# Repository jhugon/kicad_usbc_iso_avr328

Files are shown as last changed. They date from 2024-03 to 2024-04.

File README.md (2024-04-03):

# KiCad USB-C isolated ATmega328

A USB-C to serial converter connected through opto-isolators to an ATmega328.
Power for the isolated side comes through another USB-C port.

All runs on the 4V DC that comes through the USB ports and everything is
through-hole.

Notable parts are the USB-serial converter, a MCP2221A-I/P, the isolators,
ACPL-772L-000E, and the microcontroller, ATmega328P-PU.

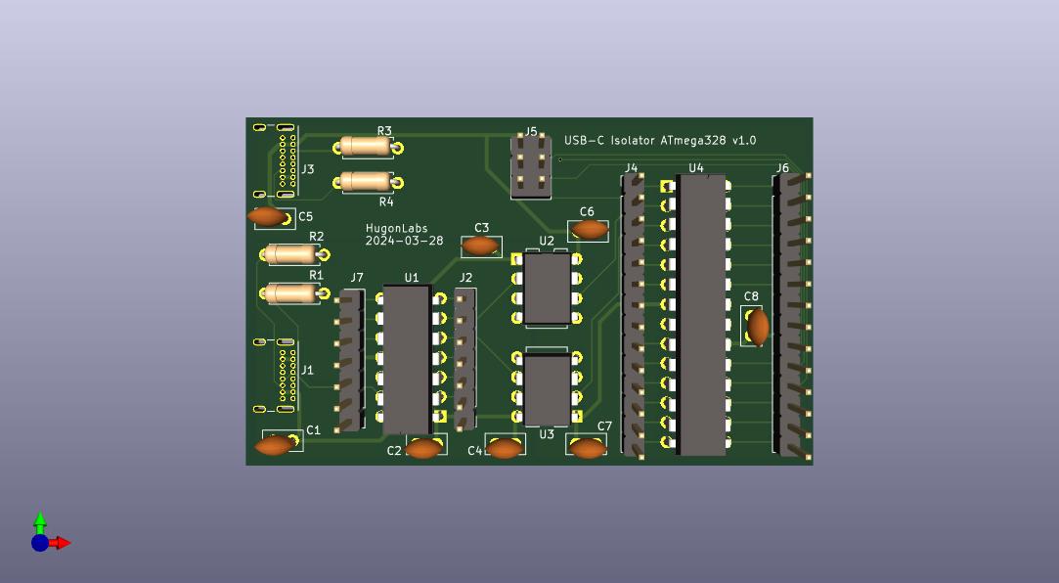
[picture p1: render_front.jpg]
Front PCB render


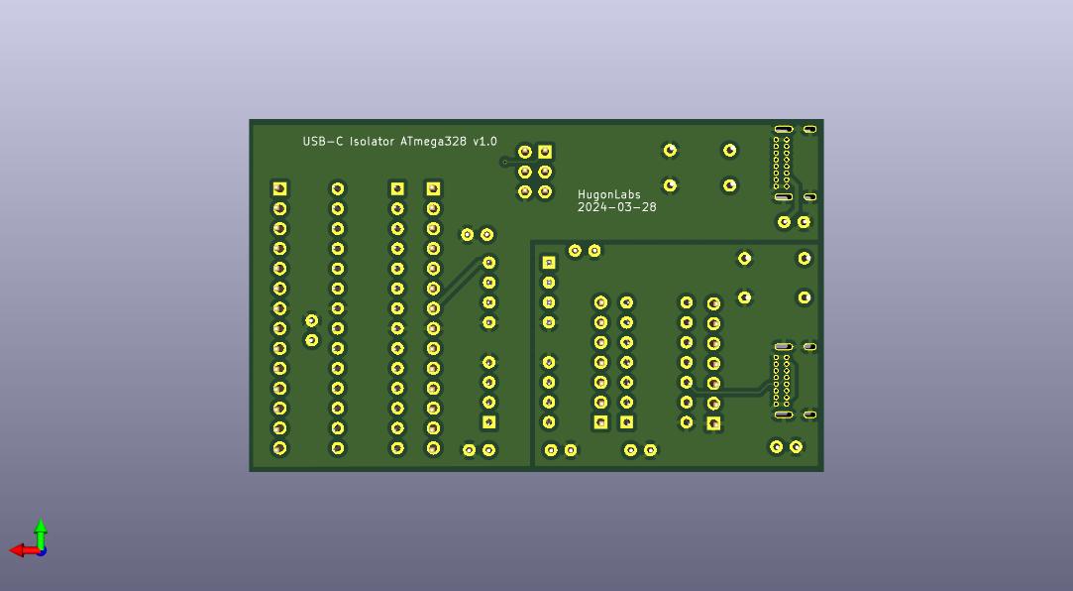
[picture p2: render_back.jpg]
Back PCB render


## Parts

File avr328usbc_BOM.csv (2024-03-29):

Reference | Value | Datasheet | Footprint | Qty | DNP | Description | MFR Part Num | MFR
C1,C5 | 10u | ~ | Capacitor_THT:C_Disc_D5.0mm_W2.5mm_P2.50mm | 2 |  | Unpolarized capacitor | FG14X7R1A106KRT00 | TDK
C2,C3,C4,C6,C7,C8 | 0u1 | ~ | Capacitor_THT:C_Disc_D5.0mm_W2.5mm_P2.50mm | 6 |  | Unpolarized capacitor | FG18X7R1H104KNT00 | TDK
J1,J3 | USB-C THT | https://www.usb.org/sites/default/files/documents/usb_type-c.zip | AAAA_Project_Library:USB_C_Receptacle_GCT_USB4085_Reduced_Pad_Size | 2 |  | USB 2.0-only 16P Type-C Receptacle connector | USB4085 | GCT
J2,J7 | MCP Debug Header | ~ | Connector_PinHeader_2.54mm:PinHeader_1x07_P2.54mm_Vertical | 2 | DNP | Generic connector, single row, 01x07, script generated (kicad-library-utils/schlib/autogen/connector/) | 9-146280-0 | TE Connectivity
J4,J6 | Conn_01x14_MountingPin | ~ | Connector_PinHeader_2.54mm:PinHeader_1x14_P2.54mm_Vertical | 2 | DNP | Generic connector, single row, 01x14, script generated (kicad-library-utils/schlib/autogen/connector/) | 9-146280-0 | TE Connectivity
J5 | AVR-ISP-6 | ~ | Connector_PinHeader_2.54mm:PinHeader_2x03_P2.54mm_Vertical | 1 |  | Atmel 6-pin ISP connector | 90130-1206 | Molex
R1,R2,R3,R4 | 5k1 | ~ | Resistor_THT:R_Axial_DIN0207_L6.3mm_D2.5mm_P7.62mm_Horizontal | 4 |  | 20% or better from USB Spec | MF1/4LCT52R512J | KOA Speer
U1 | MCP2221AxP | http://ww1.microchip.com/downloads/en/DeviceDoc/20005565B.pdf | Package_DIP:DIP-14_W7.62mm | 1 |  | USB to I2C/UART Protocol Converter with GPIO, DIP-14 | MCP2221A-I/P | Microchip
U2,U3 | ACPL-772L-000E | https://www.broadcom.com/products/optocouplers/industrial-plastic/digital-optocouplers/high-speed-cmos/acpl-772l-000e | Package_DIP:DIP-8_W7.62mm | 2 |  | High Speed CMOS Optocoupler in DIP 8 | ACPL-772L-000E | Broadcom
U4 | ATmega328P-P | http://ww1.microchip.com/downloads/en/DeviceDoc/ATmega328_P%20AVR%20MCU%20with%20picoPower%20Technology%20Data%20Sheet%2040001984A.pdf | Package_DIP:DIP-28_W7.62mm | 1 |  | 20MHz, 32kB Flash, 2kB SRAM, 1kB EEPROM, DIP-28 | ATmega328P-PU | Microchip

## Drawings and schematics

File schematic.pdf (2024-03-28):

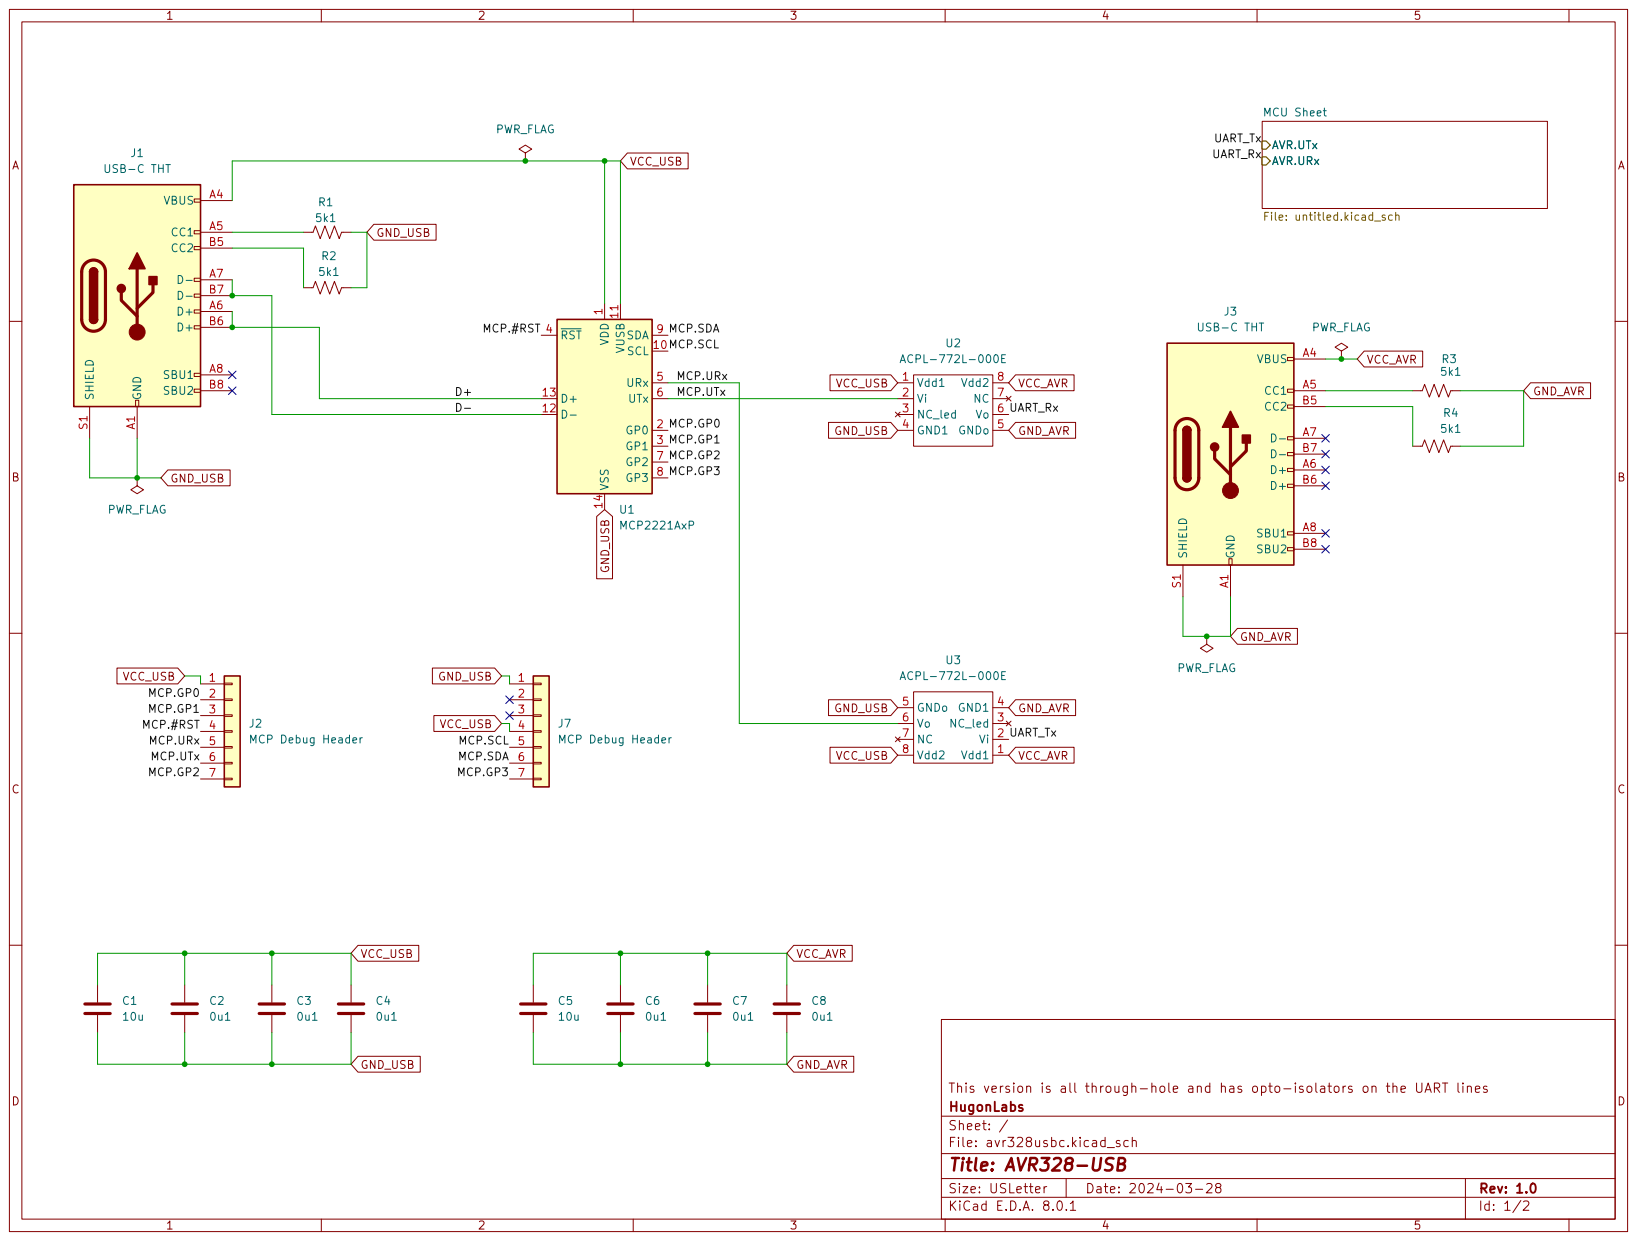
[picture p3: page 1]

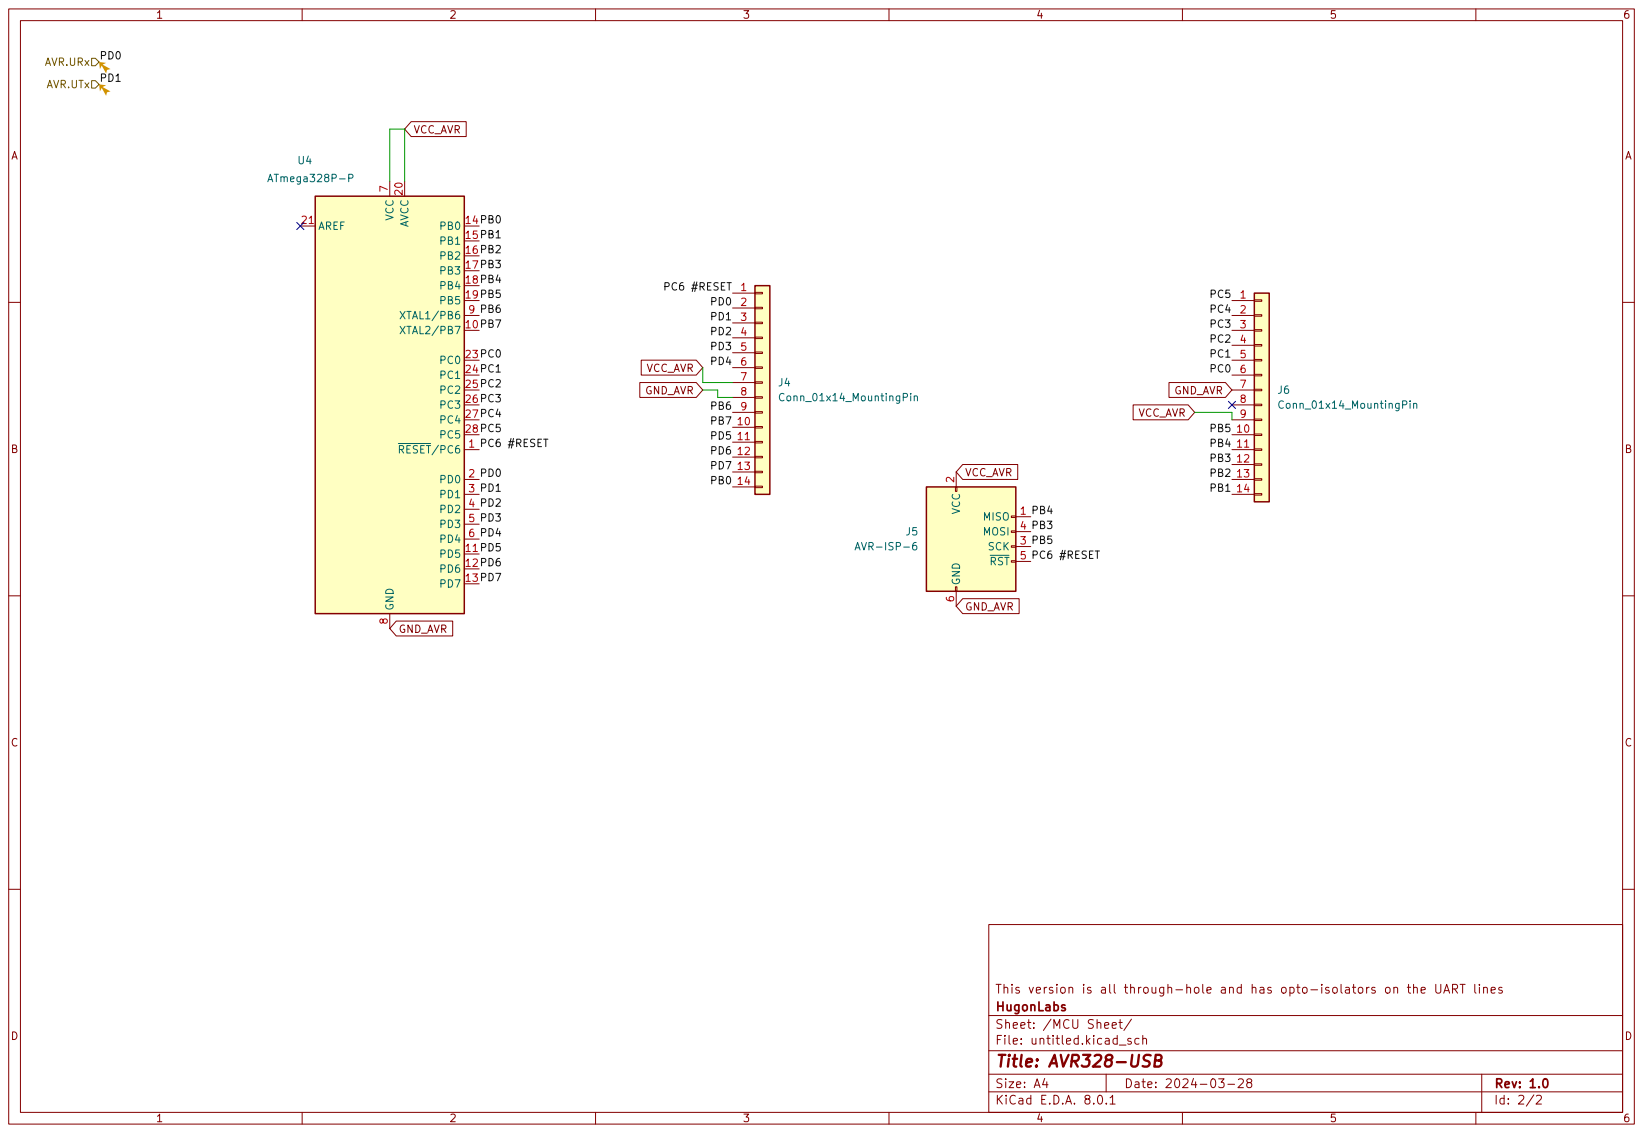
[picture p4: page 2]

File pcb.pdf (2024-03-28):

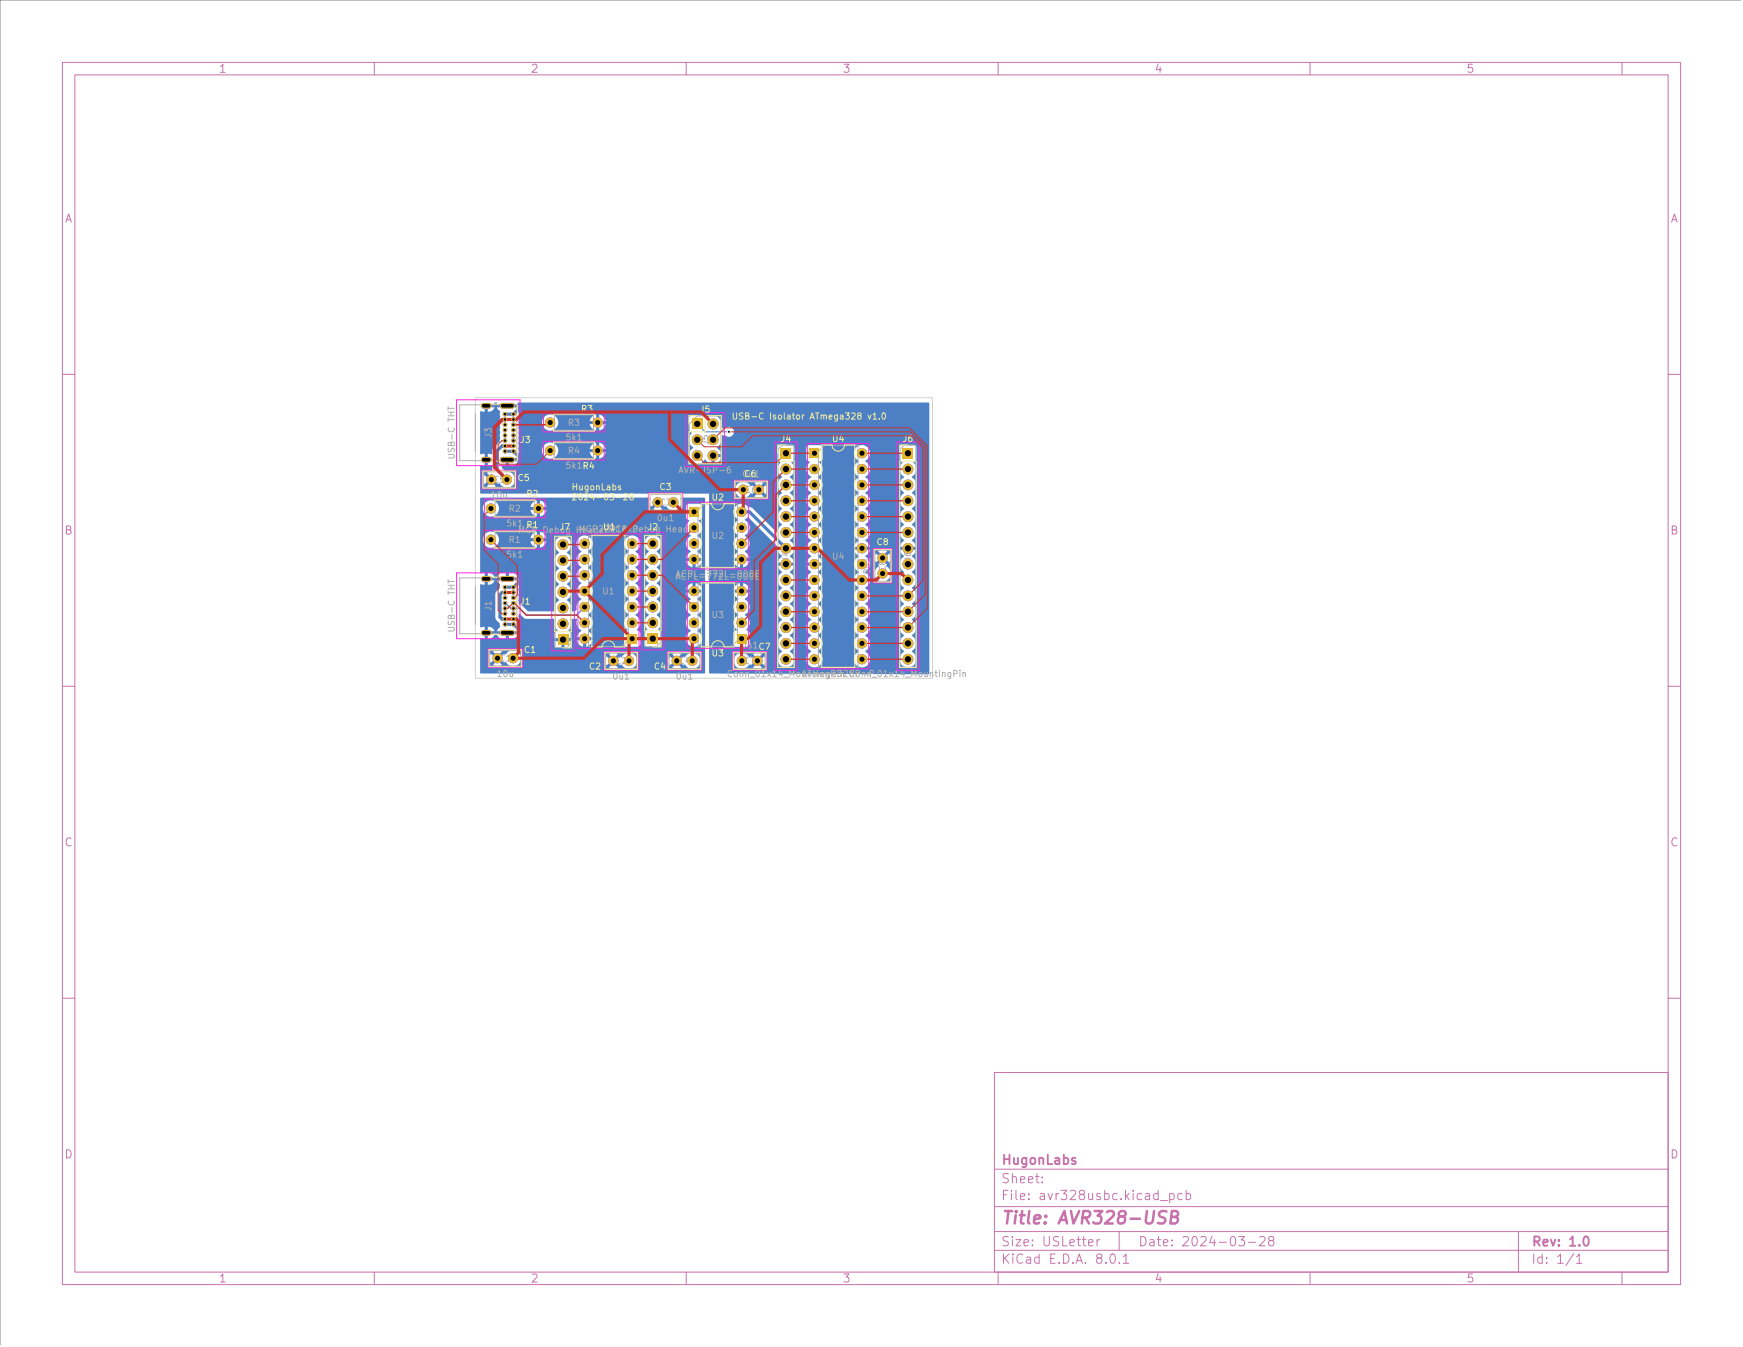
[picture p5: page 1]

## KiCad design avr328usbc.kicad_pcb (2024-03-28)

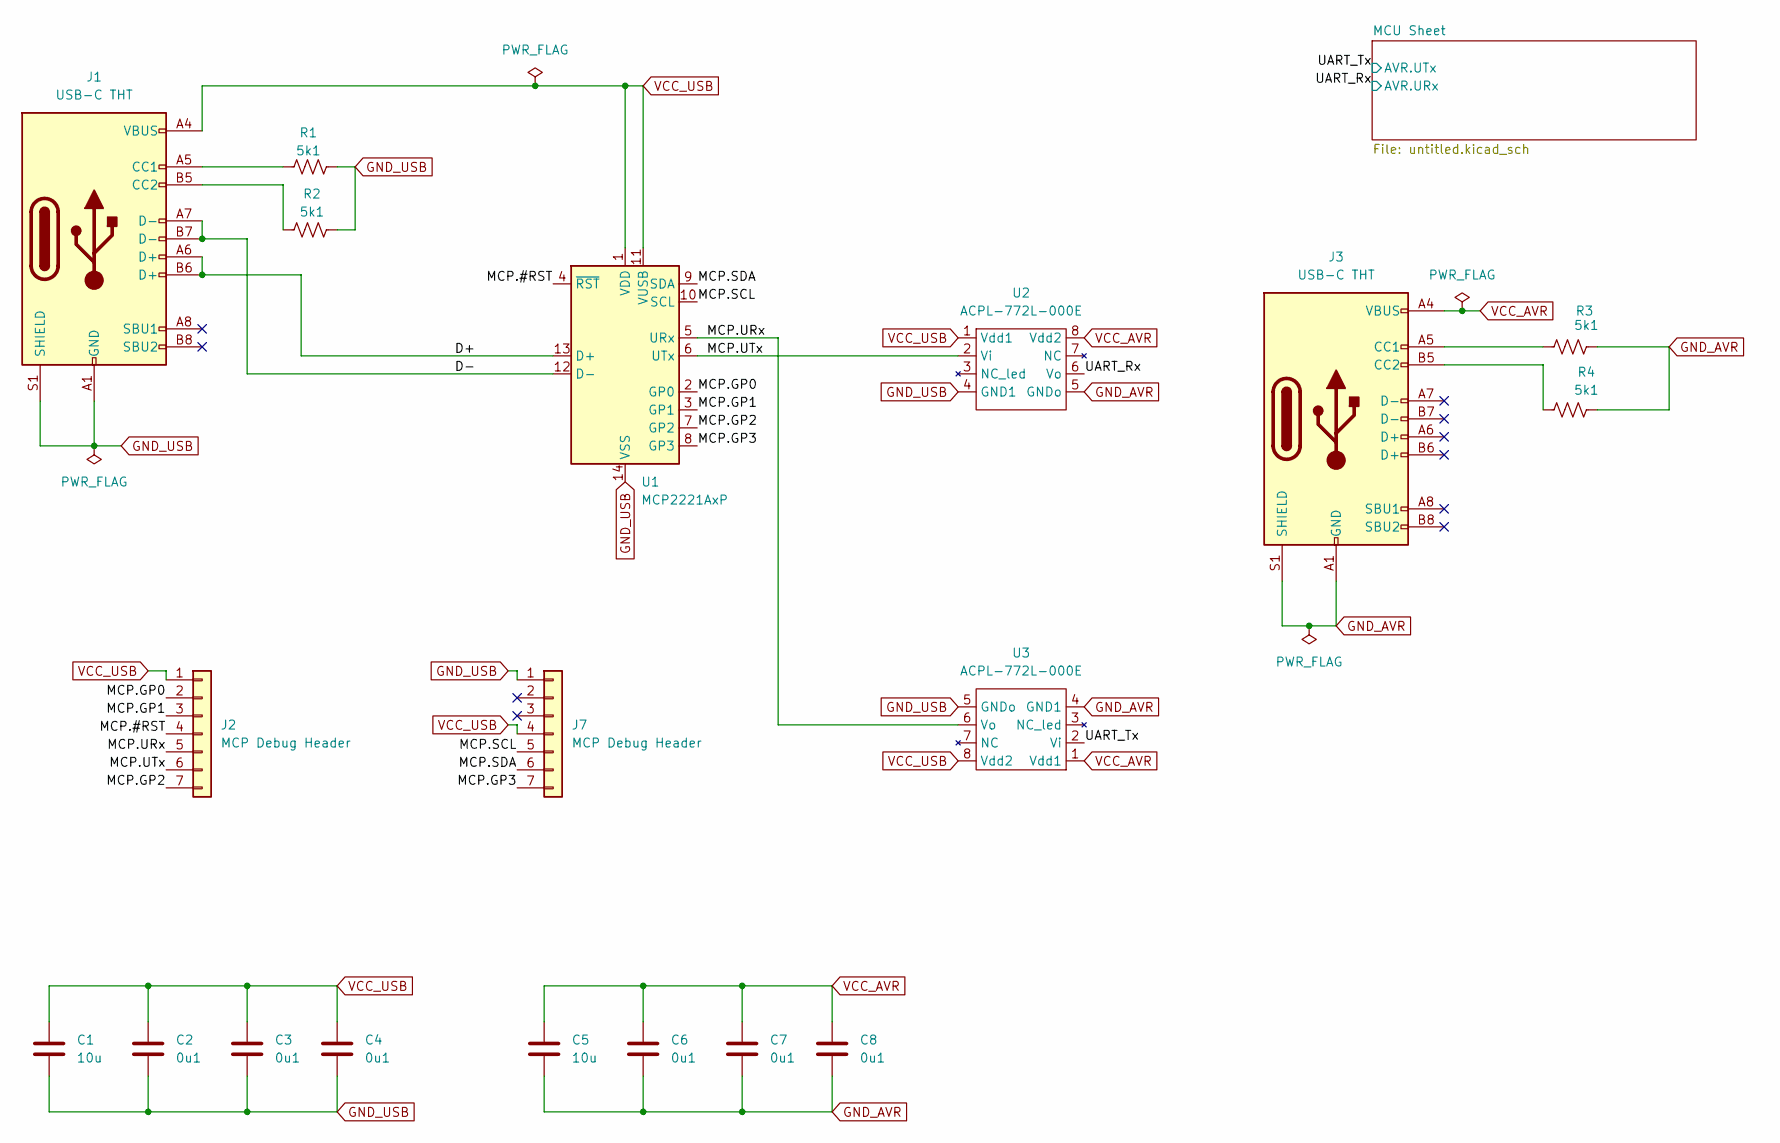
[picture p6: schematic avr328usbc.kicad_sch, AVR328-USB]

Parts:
C1, C5: 10u; C_Disc_D5.0mm_W2.5mm_P2.50mm; MFR Part Num FG14X7R1A106KRT00
C2, C3, C4, C6, C7, C8: 0u1; C_Disc_D5.0mm_W2.5mm_P2.50mm; MFR Part Num FG18X7R1H104KNT00
J1, J3: USB-C THT; USB_C_Receptacle_GCT_USB4085_Reduced_Pad_Size; MFR Part Num USB4085
J2, J7: MCP Debug Header; PinHeader_1x07_P2.54mm_Vertical; MFR Part Num 825433-7
R1, R2, R3, R4: 5k1; R_Axial_DIN0207_L6.3mm_D2.5mm_P7.62mm_Horizontal; MFR Part Num MF1/4LCT52R512J
U1: MCP2221AxP; DIP-14_W7.62mm; MFR Part Num MCP2221A-I/P
U2, U3: ACPL-772L-000E; DIP-8_W7.62mm; MFR Part Num ACPL-772L-000E

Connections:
/D+: J1.A6 (D+), J1.B6 (D+), U1.13 (D+)
/D-: J1.A7 (D-), J1.B7 (D-), U1.12 (D-)
/MCP.#RST: J2.4, U1.4 (~RST)
/MCP.GP0: J2.2, U1.2 (GP0)
/MCP.GP1: J2.3, U1.3 (GP1)
/MCP.GP2: J2.7, U1.7 (GP2)
/MCP.GP3: J7.7, U1.8 (GP3)
/MCP.SCL: J7.5, U1.10 (SCL)
/MCP.SDA: J7.6, U1.9 (SDA)
/MCP.URx: J2.5, U1.5 (URx), U3.6 (Vo)
/MCP.UTx: J2.6, U1.6 (UTx), U2.2 (Vi)
/UART_Rx: U2.6 (Vo); also elsewhere on the board
/UART_Tx: U3.2 (Vi); also elsewhere on the board
GND_AVR: C5.1, C6.1, C7.1, C8.1, J3.A1 (GND), J3.A12 (GND), J3.B1 (GND), J3.B12 (GND), J3.S1 (SHIELD), R3.2, R4.2, U2.5 (GNDo), U3.4 (GND1); also elsewhere on the board
GND_USB: C1.1, C2.1, C3.1, C4.1, J1.A1 (GND), J1.A12 (GND), J1.B1 (GND), J1.B12 (GND), J1.S1 (SHIELD), J7.1, R1.2, R2.2, U1.14 (VSS), U2.4 (GND1), U3.5 (GNDo)
unnamed: J1.A5 (CC1), R1.1
unnamed: J1.B5 (CC2), R2.1
unnamed: J3.A5 (CC1), R3.1
unnamed: J3.B5 (CC2), R4.1
VCC_AVR: C5.2, C6.2, C7.2, C8.2, J3.A4 (VBUS), J3.A9 (VBUS), J3.B4 (VBUS), J3.B9 (VBUS), U2.8 (Vdd2), U3.1 (Vdd1); also elsewhere on the board
VCC_USB: C1.2, C2.2, C3.2, C4.2, J1.A4 (VBUS), J1.A9 (VBUS), J1.B4 (VBUS), J1.B9 (VBUS), J2.1, J7.4, U1.1 (VDD), U1.11 (VUSB), U2.1 (Vdd1), U3.8 (Vdd2)

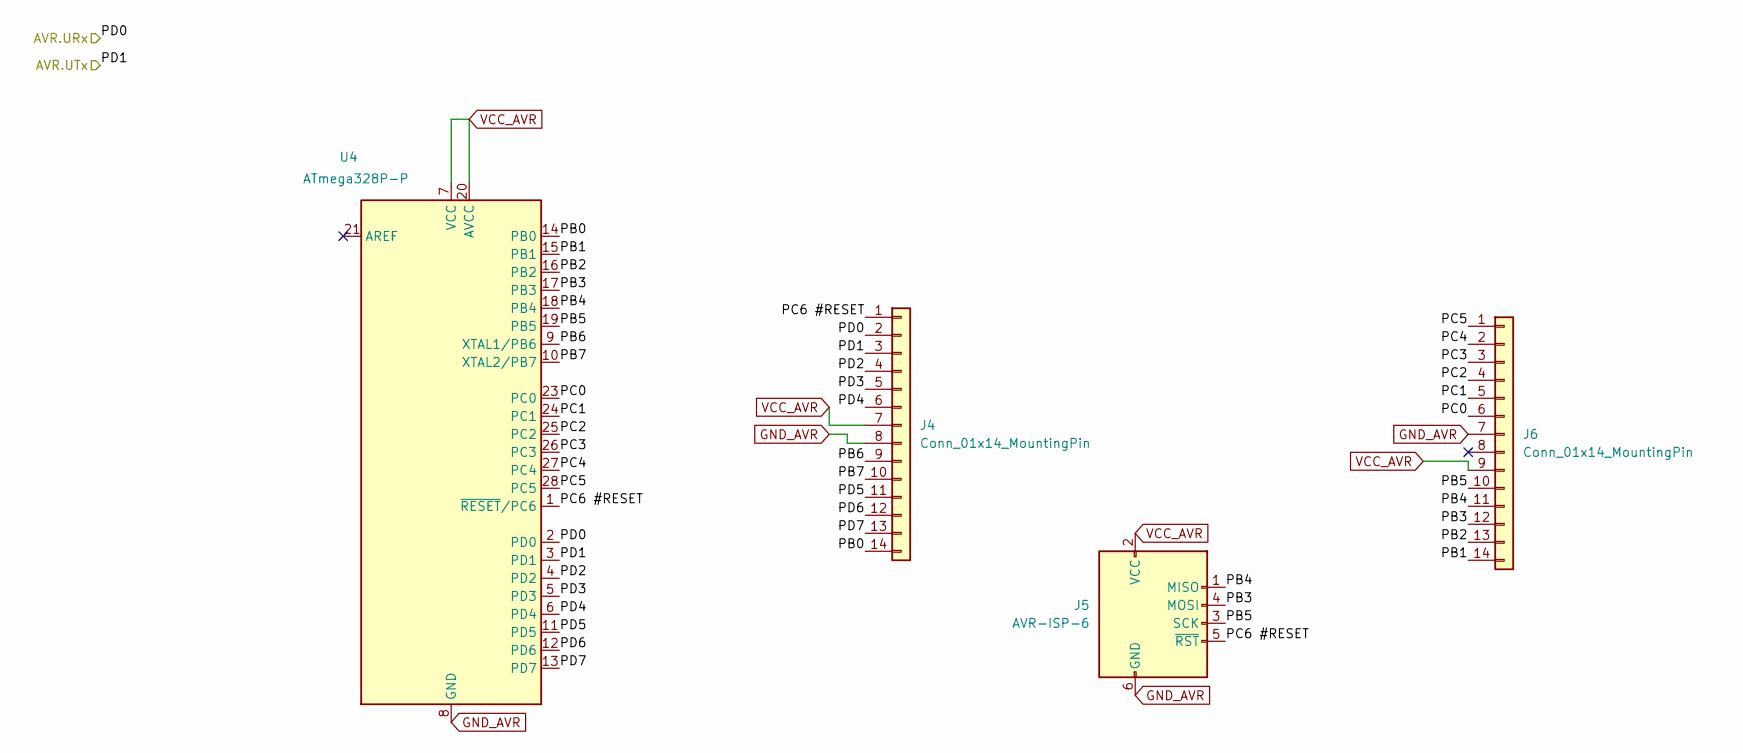
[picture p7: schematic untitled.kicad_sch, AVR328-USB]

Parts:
J4, J6: Conn_01x14_MountingPin; PinHeader_1x14_P2.54mm_Vertical
J5: AVR-ISP-6; PinHeader_2x03_P2.54mm_Vertical
U4: ATmega328P-P; DIP-28_W7.62mm; MFR Part Num ATmega328P-PU

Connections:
/MCU Sheet/PB0: J4.14, U4.14 (PB0)
/MCU Sheet/PB1: J6.14, U4.15 (PB1)
/MCU Sheet/PB2: J6.13, U4.16 (PB2)
/MCU Sheet/PB3: J5.4 (MOSI), J6.12, U4.17 (PB3)
/MCU Sheet/PB4: J5.1 (MISO), J6.11, U4.18 (PB4)
/MCU Sheet/PB5: J5.3 (SCK), J6.10, U4.19 (PB5)
/MCU Sheet/PB6: J4.9, U4.9 (XTAL1/PB6)
/MCU Sheet/PB7: J4.10, U4.10 (XTAL2/PB7)
/MCU Sheet/PC0: J6.6, U4.23 (PC0)
/MCU Sheet/PC1: J6.5, U4.24 (PC1)
/MCU Sheet/PC2: J6.4, U4.25 (PC2)
/MCU Sheet/PC3: J6.3, U4.26 (PC3)
/MCU Sheet/PC4: J6.2, U4.27 (PC4)
/MCU Sheet/PC5: J6.1, U4.28 (PC5)
/MCU Sheet/PC6 #RESET: J4.1, J5.5 (~RST), U4.1 (~RESET/PC6)
/MCU Sheet/PD2: J4.4, U4.4 (PD2)
/MCU Sheet/PD3: J4.5, U4.5 (PD3)
/MCU Sheet/PD4: J4.6, U4.6 (PD4)
/MCU Sheet/PD5: J4.11, U4.11 (PD5)
/MCU Sheet/PD6: J4.12, U4.12 (PD6)
/MCU Sheet/PD7: J4.13, U4.13 (PD7)
/UART_Rx: J4.2, U4.2 (PD0); also elsewhere on the board
/UART_Tx: J4.3, U4.3 (PD1); also elsewhere on the board
GND_AVR: J4.8, J5.6 (GND), J6.7, U4.8 (GND), U4.22 (GND); also elsewhere on the board
VCC_AVR: J4.7, J5.2 (VCC), J6.9, U4.7 (VCC), U4.20 (AVCC); also elsewhere on the board

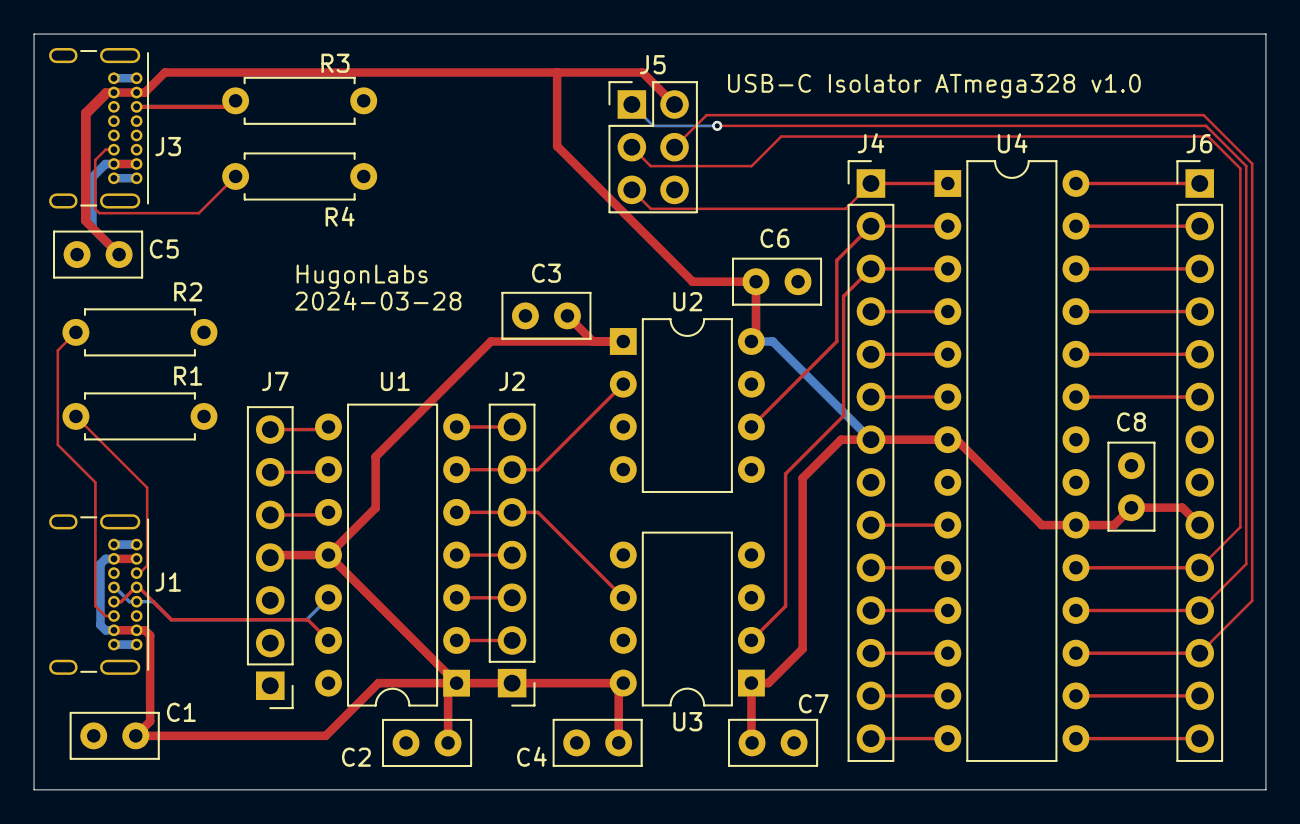
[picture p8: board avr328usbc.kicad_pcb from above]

Board: 2 copper layers, 73.3 x 45.0 mm, 23 parts (0 on the bottom side), 42 nets.

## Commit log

2024-03-04 initial commit of project
    schematic has some work done
    [avr328usbc.kicad_pcb, avr328usbc.kicad_sch]
2024-03-07 schematic: added a bunch of labels & changed pwer to labels
    [avr328usbc.kicad_sch]
2024-03-08 added mcu sheet and global labels for power
    [avr328usbc.kicad_sch, untitled.kicad_sch]
2024-03-08 sch: finished with main components
    [avr328usbc.kicad_sch, untitled.kicad_sch]
2024-03-08 sch: done, footprints added as well
    [avr328usbc.kicad_sch, untitled.kicad_sch]
2024-03-08 working on pcb
    [avr328usbc.kicad_pcb, avr328usbc.kicad_sch]
2024-03-27 finished converting schematic to correct USBC and pin headers
    Symbols didn't match the footprints
    [avr328usbc.kicad_pcb, avr328usbc.kicad_sch, untitled.kicad_sch]
2024-03-27 pcb footprints placed and locked
    [avr328usbc.kicad_pcb]
2024-03-28 added more detail to BOM for resistors/caps
    [avr328usbc.kicad_sch]
2024-03-28 routed most non-header signals
    [avr328usbc.kicad_pcb]
2024-03-28 reordered pins and routed MCP header
    [avr328usbc.kicad_pcb, avr328usbc.kicad_sch]
2024-03-28 changed AVR header into 2 headers mirroring pinout
    [untitled.kicad_sch]
2024-03-28 changed MCP header into two headers mirroring part
    also rearanged components on board
    [avr328usbc.kicad_pcb, avr328usbc.kicad_sch, untitled.kicad_sch]
2024-03-28 much of board routed
    [avr328usbc.kicad_pcb]
2024-03-28 first pass at ground plane
    [avr328usbc.kicad_pcb]
2024-03-28 after first look at DRC
    [avr328usbc.kicad_pcb]
2024-03-28 modified USB-C footprint to follow clearence rules at OSH
    Now almost all DRCs pass
    [avr328usbc.kicad_pcb, avr328usbc.kicad_sch]
2024-03-28 Removed off-board silk from USB and tweaked silk refid pos
    No more silk warnings or errors!
    [avr328usbc.kicad_pcb]
2024-03-28 Added silk text to board
    [avr328usbc.kicad_pcb]
2024-03-28 final version edits
    [avr328usbc.kicad_pcb, avr328usbc.kicad_sch, untitled.kicad_sch]
2024-03-28 Add schematic, pcb, and render jpgs/pdfs
2024-03-29 Finished and exported BOM
    [avr328usbc.kicad_sch, avr328usbc_BOM.csv, untitled.kicad_sch]
2024-03-29 fixed bug in BOM
    [avr328usbc_BOM.csv, untitled.kicad_sch]
